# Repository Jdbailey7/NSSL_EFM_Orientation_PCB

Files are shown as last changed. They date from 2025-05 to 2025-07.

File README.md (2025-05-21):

# NSSL EFM Orientation PCB

In the paddle opposite the motor driver, an orientation sensor based on a simple IMU  
provides rough data on the instrument’s orientation over time. This allows analysis  
of pendulum motion and other movements of the full instrument package. The system is  
designed for easy sensor replacement, and all orientation data are logged to a  
microSD card.

See the [main instrument repo](https://github.com/LeemanGeophysicalLLC/NSSL_EFM_Instrument)
for documentation and the rest of the instrument.

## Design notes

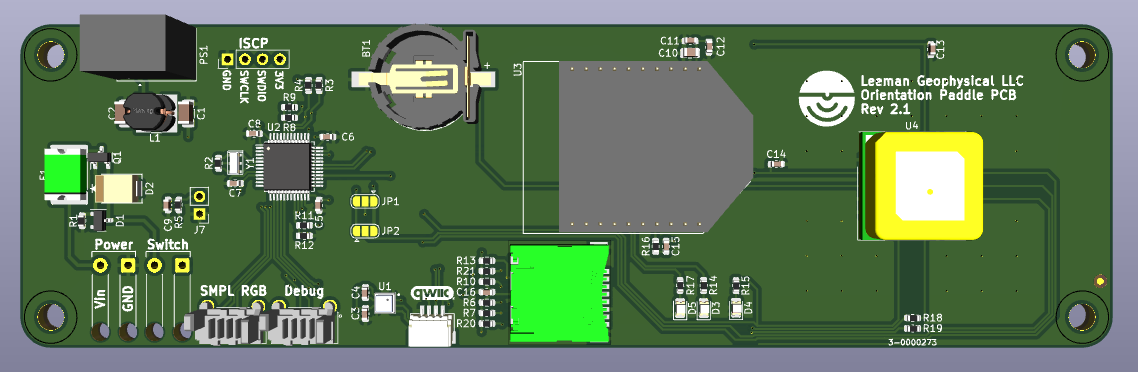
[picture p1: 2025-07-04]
Renders/pcb_front.png

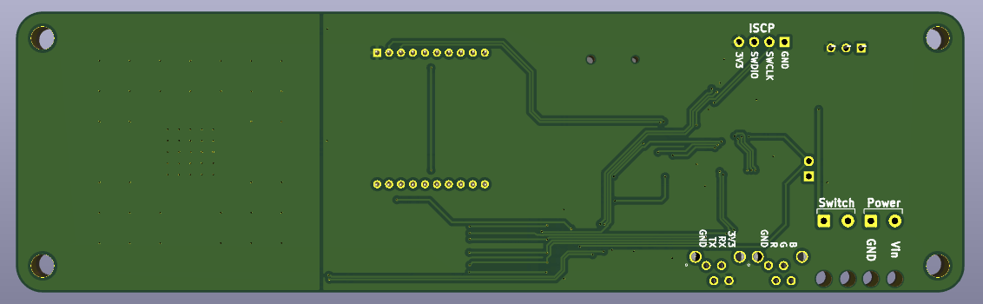
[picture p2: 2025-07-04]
Renders/pcb_back.png

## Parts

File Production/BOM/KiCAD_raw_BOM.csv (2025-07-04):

Reference | Value | Internal Part Number | PValue | Populated
BT1 | 1-0000246 | 1-0000246 | CR1220 | 1
C1 | 1-0000136 | 1-0000136 | 4.7uF | 1
C2 | 1-0000136 | 1-0000136 | 4.7uF | 1
C3 | 1-0000007 | 1-0000007 | 0.1uF | 0
C4 | 1-0000007 | 1-0000007 | 0.1uF | 0
C5 | 1-0000007 | 1-0000007 | 0.1uF | 1
C6 | 1-0000007 | 1-0000007 | 0.1uF | 1
C7 | 1-0000007 | 1-0000007 | 0.1uF | 1
C8 | 1-0000007 | 1-0000007 | 0.1uF | 1
C9 | 1-0000007 | 1-0000007 | 0.1uF | 1
C10 | 1-0000075 | 1-0000075 | 10uF | 0
C11 | 1-0000018 | 1-0000018 | 1uF | 0
C12 | 1-0000007 | 1-0000007 | 0.1uF | 0
C13 | 1-0000007 | 1-0000007 | 0.1uF | 1
C14 | 1-0000007 | 1-0000007 | 0.1uF | 1
C15 | 1-0000007 | 1-0000007 | 0.1uF | 0
C16 | 1-0000007 | 1-0000007 | 0.1uF | 1
D1 | 1-0001672 | 1-0001672 | BZX84C15 | 1
D2 | 1-0001537 | 1-0001537 | SMBJ64A | 1
D3 | 1-0000599 | 1-0000599 | Blue | 0
D4 | 1-0000601 | 1-0000601 | Yellow | 1
D5 | 1-0000601 | 1-0000601 | Yellow | 0
F1 | 1-0001517 | 1-0001517 | 1A | 1
FID1 | Fiducial_1mm_2mm | 0-0000000 | Fiducial | 0
FID2 | Fiducial_1mm_2mm | 0-0000000 | Fiducial | 0
J1 | 1-0001205 | 1-0001205 | Qwiic | 1
J2 | 1-0001156 | 1-0001156 | 4 Pos | 1
J3 | 1-0001156 | 1-0001156 | 4 Pos | 1
J4 | NP_Conn_01x02_Relief | 0-0000000 | NP_Conn_01x02 | 0
J5 | NP_Conn_01x02_Relief | 0-0000000 | NP_Conn_01x02 | 0
J6 | NP_Conn_01x04 | 0-0000000 | ISCP | 0
J7 | NP_Conn_01x02 | 0-0000000 | Reset | 0
J8 | 1-0000050 | 1-0000050 | XBee Socket | 0
J9 | 1-0000190 | 1-0000190 | DM3CS | 1
JP1 | SolderJumper_3_Bridged12 | 0-0000000 | Solder Jumper | 0
JP2 | SolderJumper_3_Bridged12 | 0-0000000 | Solder Jumper | 0
L1 | 1-0000931 | 1-0000931 | 3.3uH | 1
PCB1 | barepcb | 3-0000273 | Bare PCB | 1
PS1 | 1-0000727 | 1-0000727 | TSR 0.5 | 1
Q1 | 1-0001670 | 1-0001670 | SQ2337ES | 1
R1 | 1-0000174 | 1-0000174 | 100k | 1
R2 | 1-0000009 | 1-0000009 | NP | 0
R3 | 1-0000010 | 1-0000010 | 10k | 1
R4 | 1-0000010 | 1-0000010 | 10k | 1
R5 | 1-0000010 | 1-0000010 | 10k | 1
R6 | 1-0000010 | 1-0000010 | 10k | 1
R7 | 1-0000010 | 1-0000010 | 10k | 1
R8 | 1-0000006 | 1-0000006 | NP | 0
R9 | 1-0000174 | 1-0000174 | 100k | 1
R10 | 1-0000010 | 1-0000010 | 10k | 1
R11 | 1-0000006 | 1-0000006 | NP | 0
R12 | 1-0000174 | 1-0000174 | 100k | 1
R13 | 1-0000010 | 1-0000010 | 10k | 1
R14 | 1-0000008 | 1-0000008 | 150 | 0
R15 | 1-0000008 | 1-0000008 | 150 | 1
R16 | 1-0000006 | 1-0000006 | NP | 0
R17 | 1-0000008 | 1-0000008 | 150 | 0
R18 | 1-0000006 | 1-0000006 | 0R0 | 1
R19 | 1-0000006 | 1-0000006 | 0R0 | 1
R20 | 1-0000174 | 1-0000174 | 100k | 1
R21 | 1-0000174 | 1-0000174 | 100k | 1
U1 | 1-0001471 | 1-0001471 | BME688 | 0
U2 | 1-0000207 | 1-0000207 | STM32F103 | 1
U3 | 1-0000785 | 1-0000785 | XB3-24 | 0
U4 | 1-0000446 | 1-0000446 | SAM-M8Q-0-10 | 1
Y1 | 1-0000721 | 1-0000721 | 8MHz | 1

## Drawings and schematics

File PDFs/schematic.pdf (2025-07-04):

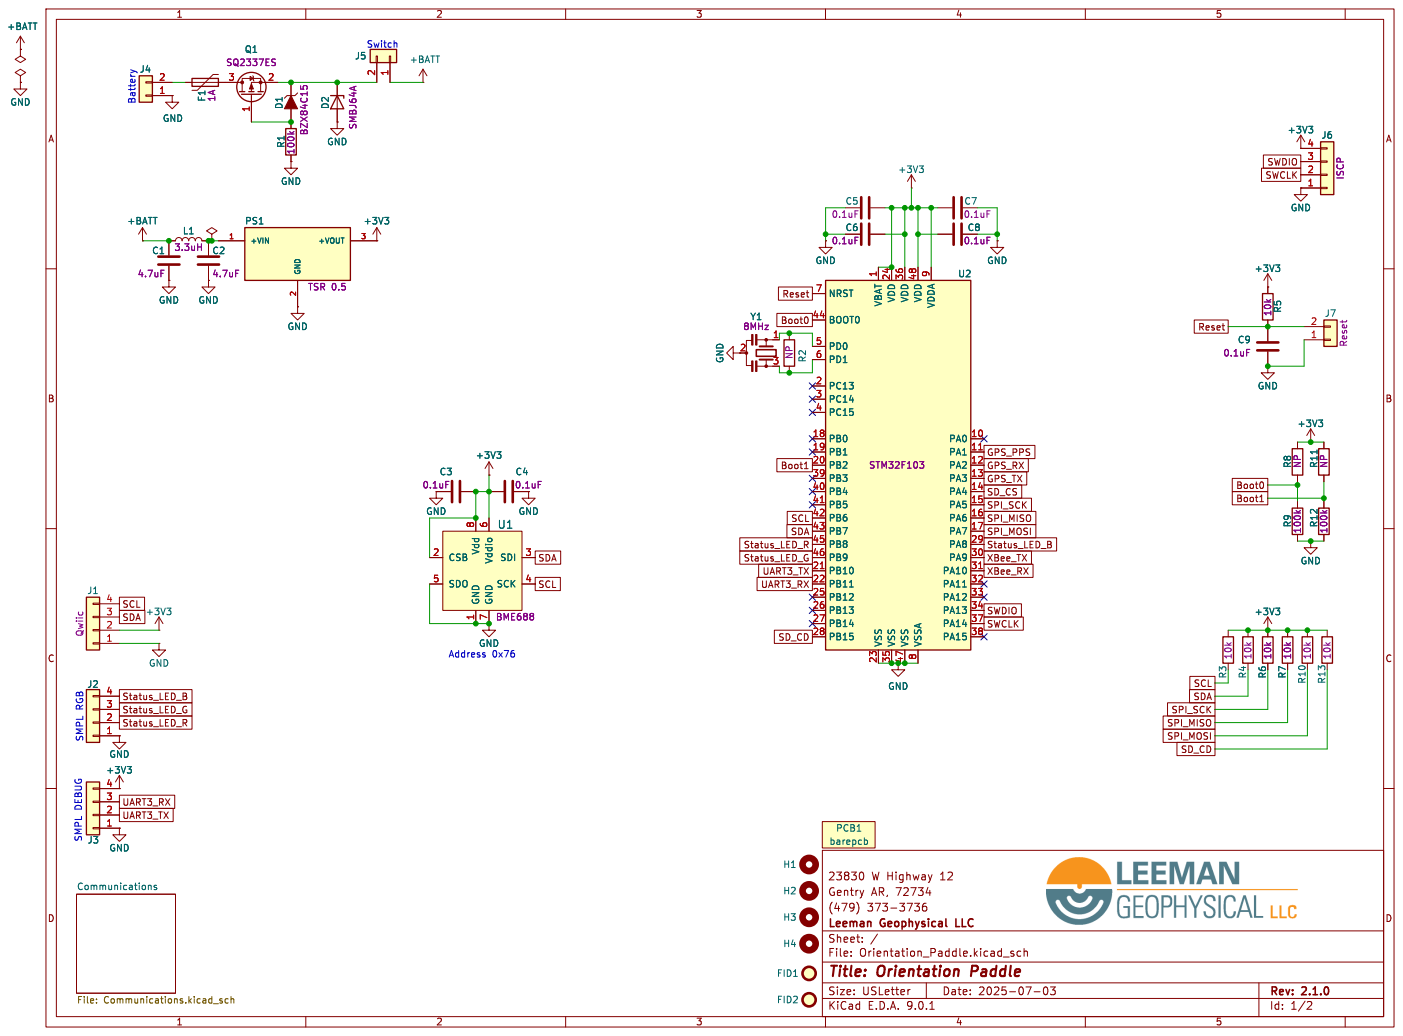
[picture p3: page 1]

Id: 1/2 Title: Orientation Paddle

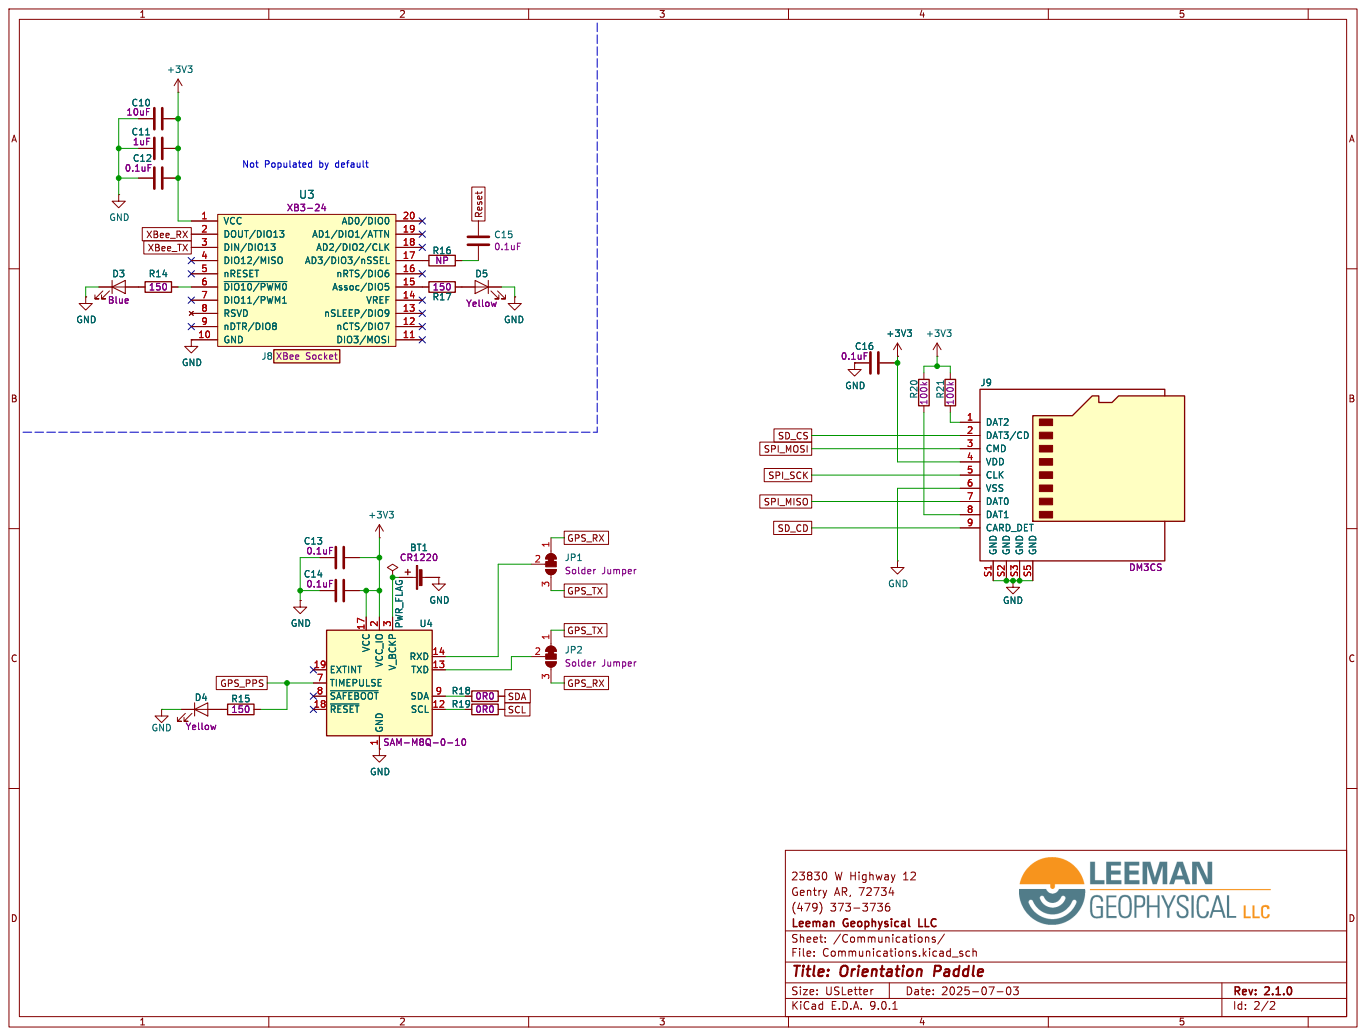
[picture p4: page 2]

J8 XBee Socket GND GND

Id: 2/2 Title: Orientation Paddle

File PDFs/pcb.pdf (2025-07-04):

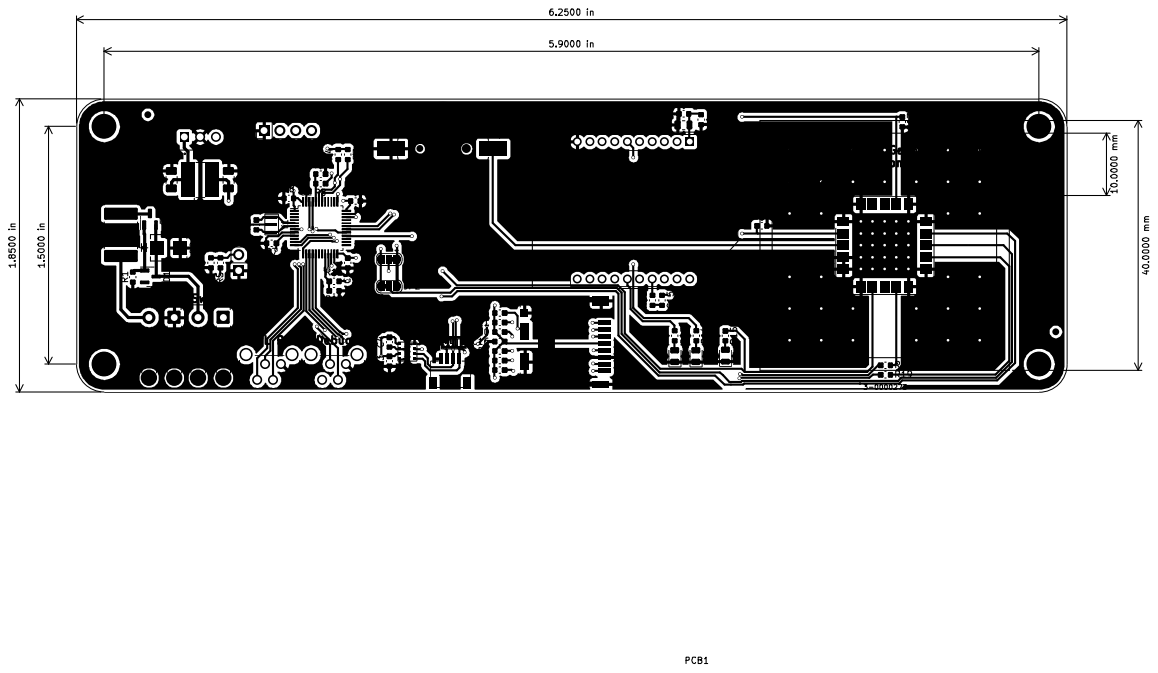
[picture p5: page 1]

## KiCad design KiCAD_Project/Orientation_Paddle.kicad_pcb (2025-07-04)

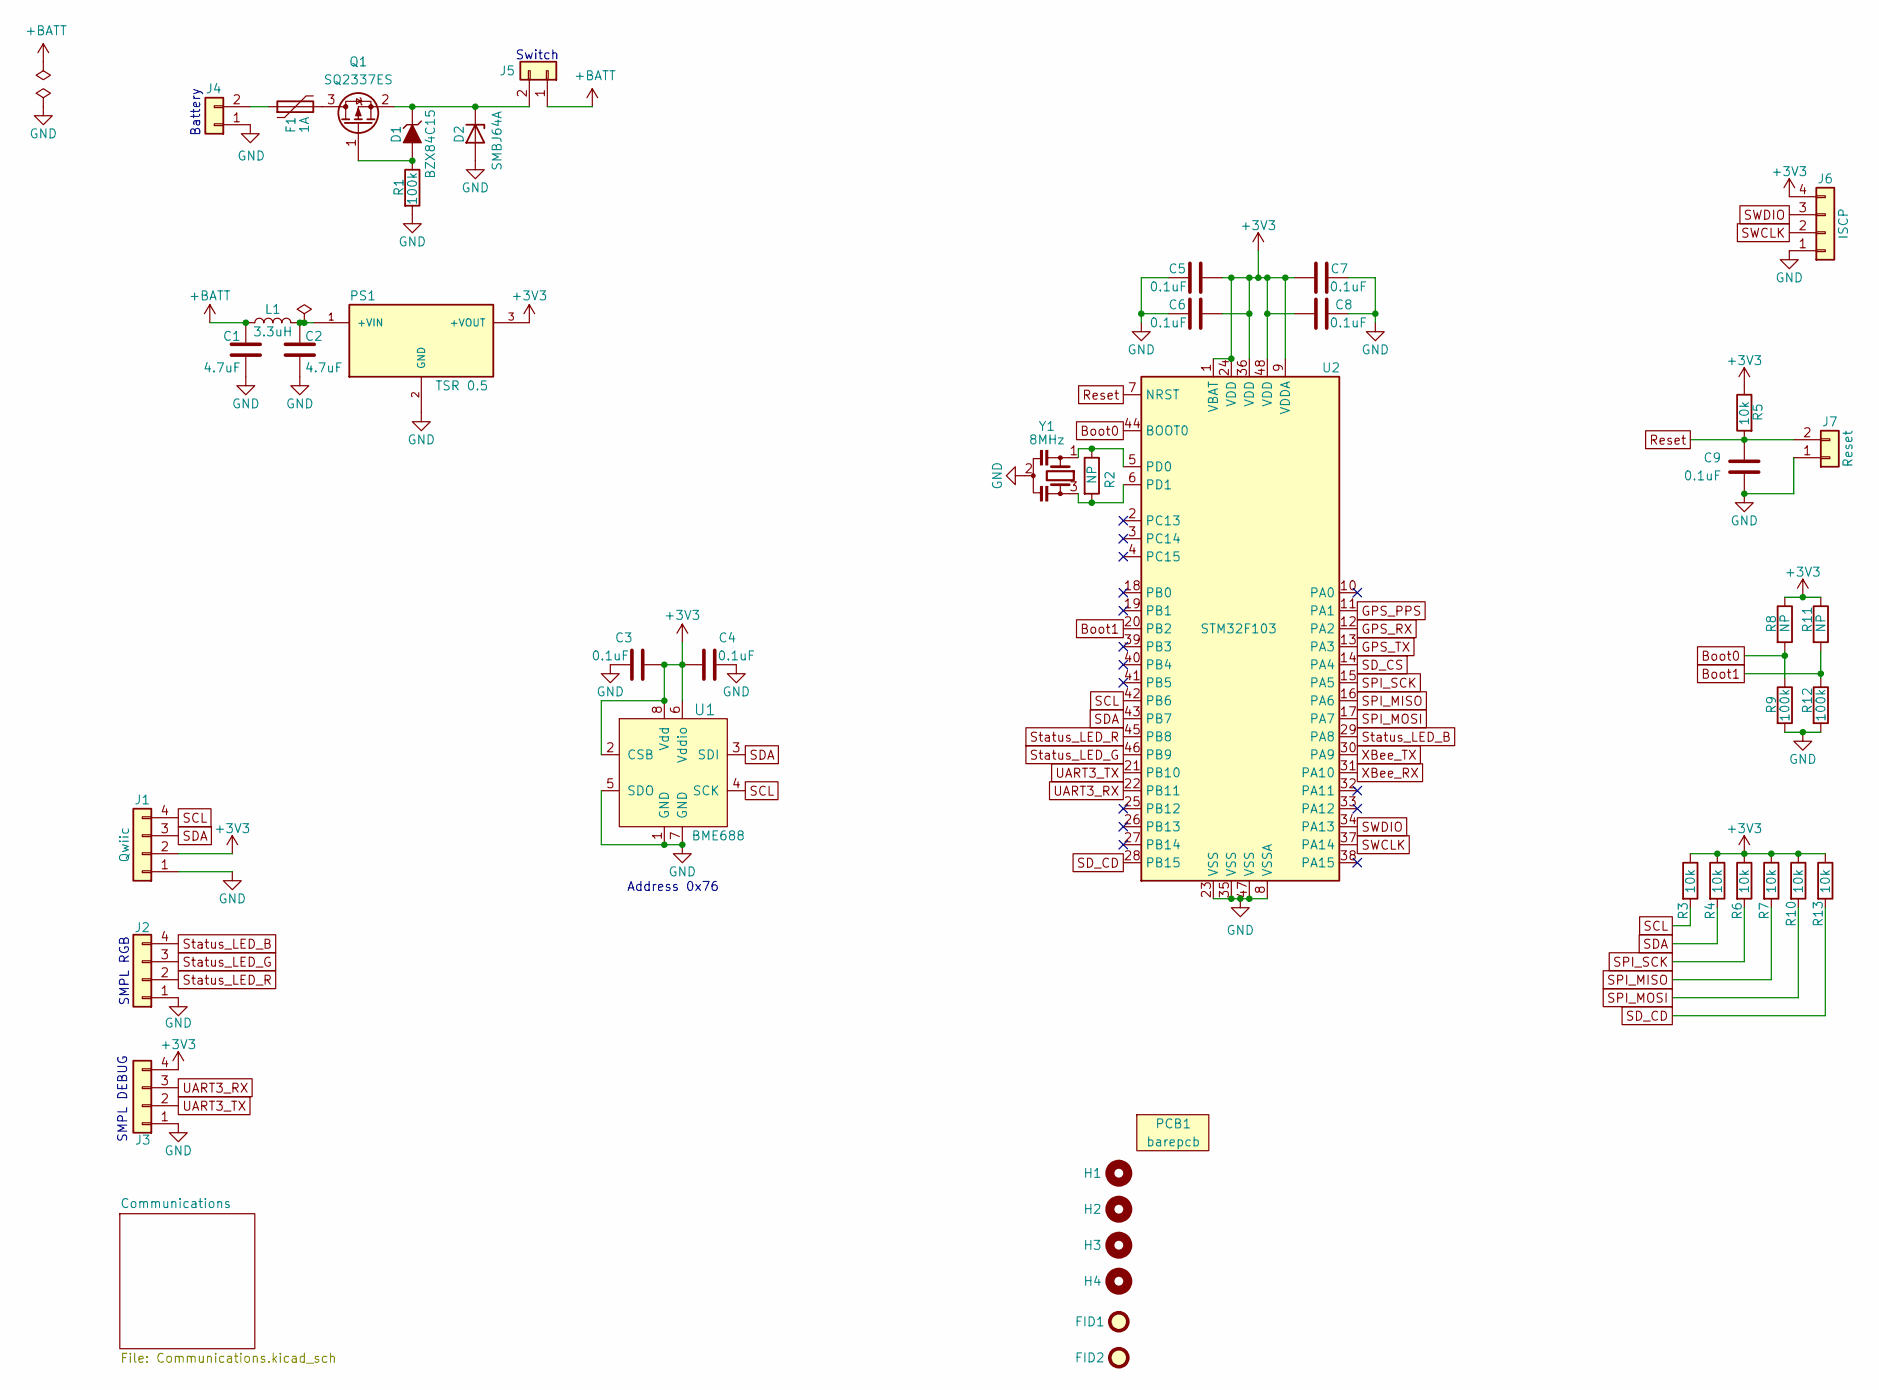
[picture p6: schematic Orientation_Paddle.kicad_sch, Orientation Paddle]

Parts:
C1, C2: 1-0000136
C3, C4, C5, C6, C7, C8, C9: 1-0000007
D1: 1-0001672
D2: 1-0001537
F1: 1-0001517
FID1, FID2: Fiducial_1mm_2mm; Fiducial_1mm_Mask2mm
H1, H2, H3, H4: Imperial6; MountingHole_imperial6
J1: 1-0001205
J2, J3: 1-0001156
J4, J5: NP_Conn_01x02_Relief; SolderWire_1x02_Relief
J6: NP_Conn_01x04; PinHeader_1x04_P2.54mm_Vertical
J7: NP_Conn_01x02; PinHeader_1x02_P2.54mm_Vertical
L1: 1-0000931
PCB1: barepcb
PS1: 1-0000727
Q1: 1-0001670
R1, R9, R12: 1-0000174
R2: 1-0000009
R3, R4, R5, R6, R7, R10, R13: 1-0000010
R8, R11: 1-0000006
U1: 1-0001471
U2: 1-0000207
Y1: 1-0000721

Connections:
+3V3: C3.2, C4.1, C5.1, C6.1, C7.1, C8.1, J1.2, J3.4, J6.4, PS1.3 (+VOUT), R3.1, R4.1, R5.1, R6.1, R7.1, R8.1, R10.1, R11.1, R13.1, U1.2 (CSB), U1.6 (Vddio), U1.8 (Vdd), U2.1 (VBAT), U2.9 (VDDA), U2.24 (VDD), U2.36 (VDD), U2.48 (VDD); also elsewhere on the board
+BATT: C1.1, J5.1, L1.1
Boot0: R8.2, R9.1, U2.44 (BOOT0)
Boot1: R11.2, R12.1, U2.20 (PB2)
GND: C1.2, C2.2, C3.1, C4.2, C5.2, C6.2, C7.2, C8.2, C9.2, D2.2 (A), J1.1, J2.1, J3.1, J4.1, J6.1, J7.1, PS1.2 (GND), R1.2, R9.2, R12.2, U1.1 (GND), U1.5 (SDO), U1.7 (GND), U2.8 (VSSA), U2.23 (VSS), U2.35 (VSS), U2.47 (VSS), Y1.2; also elsewhere on the board
GPS_PPS: U2.11 (PA1); also elsewhere on the board
GPS_RX: U2.12 (PA2); also elsewhere on the board
GPS_TX: U2.13 (PA3); also elsewhere on the board
unnamed: D1.1 (A), Q1.1 (G), R1.1
unnamed: D1.3 (K), D2.1 (K), J5.2, Q1.2 (S)
unnamed: F1.1, J4.2
unnamed: C2.1, L1.2, PS1.1 (+VIN)
unnamed: F1.2, Q1.3 (D)
unnamed: R2.1, U2.5 (PD0), Y1.1
unnamed: R2.2, U2.6 (PD1), Y1.3
Reset: C9.1, J7.2, R5.2, U2.7 (NRST); also elsewhere on the board
SCL: J1.4, R3.2, U1.4 (SCK), U2.42 (PB6); also elsewhere on the board
SDA: J1.3, R4.2, U1.3 (SDI), U2.43 (PB7); also elsewhere on the board
SD_CD: R13.2, U2.28 (PB15); also elsewhere on the board
SD_CS: U2.14 (PA4); also elsewhere on the board
SPI_MISO: R7.2, U2.16 (PA6); also elsewhere on the board
SPI_MOSI: R10.2, U2.17 (PA7); also elsewhere on the board
SPI_SCK: R6.2, U2.15 (PA5); also elsewhere on the board
SWCLK: J6.2, U2.37 (PA14)
SWDIO: J6.3, U2.34 (PA13)
Status_LED_B: J2.4, U2.29 (PA8)
Status_LED_G: J2.3, U2.46 (PB9)
Status_LED_R: J2.2, U2.45 (PB8)
UART3_RX: J3.3, U2.22 (PB11)
UART3_TX: J3.2, U2.21 (PB10)
XBee_RX: U2.31 (PA10); also elsewhere on the board
XBee_TX: U2.30 (PA9); also elsewhere on the board

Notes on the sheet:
Battery
Address 0x76
SMPL DEBUG
Switch
SMPL RGB

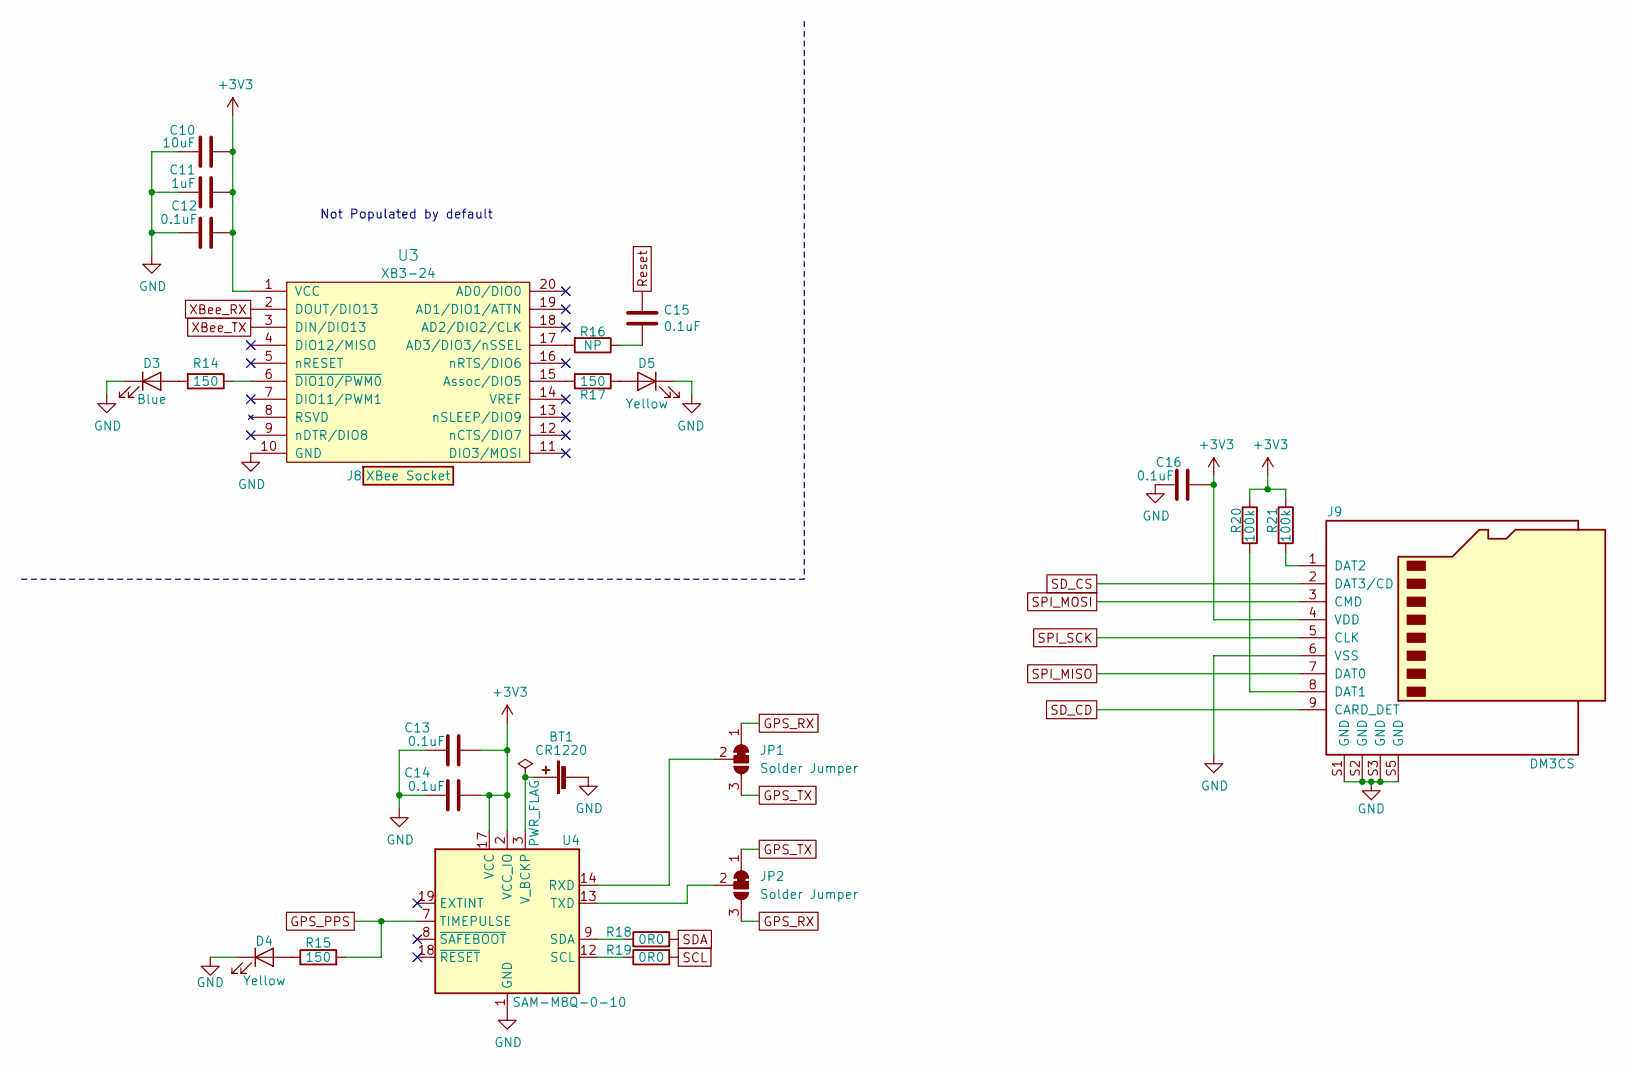
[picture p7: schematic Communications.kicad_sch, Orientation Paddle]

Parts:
BT1: 1-0000246
C10: 1-0000075
C11: 1-0000018
C12, C13, C14, C15, C16: 1-0000007
D3: 1-0000599
D4, D5: 1-0000601
J8: 1-0000050
J9: 1-0000190
JP1, JP2: SolderJumper_3_Bridged12; SolderJumper-3_P1.3mm_Bridged12_RoundedPad1.0x1.5mm
R14, R15, R17: 1-0000008
R16, R18, R19: 1-0000006
R20, R21: 1-0000174
U3: 1-0000785
U4: 1-0000446

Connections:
+3V3: C10.1, C11.1, C12.1, C13.1, C14.1, C16.2, J9.4 (VDD), R20.1, R21.1, U3.1 (VCC), U4.2 (VCC_IO), U4.17 (VCC); also elsewhere on the board
GND: BT1.2 (-), C10.2, C11.2, C12.2, C13.2, C14.2, C16.1, D3.1 (K), D4.1 (K), D5.1 (K), J9.6 (VSS), J9.S1 (GND), J9.S2 (GND), J9.S3 (GND), J9.S5 (GND), U3.10 (GND), U4.1 (GND), U4.4 (GND), U4.5 (GND), U4.6 (GND), U4.10 (GND), U4.11 (GND), U4.15 (GND), U4.16 (GND), U4.20 (GND); also elsewhere on the board
GPS_PPS: R15.2, U4.7 (TIMEPULSE); also elsewhere on the board
GPS_RX: JP1.1 (A), JP2.3 (B); also elsewhere on the board
GPS_TX: JP1.3 (B), JP2.1 (A); also elsewhere on the board
unnamed: BT1.1 (+), U4.3 (V_BCKP)
unnamed: C15.2, R16.1
unnamed: D3.2 (A), R14.2
unnamed: D4.2 (A), R15.1
unnamed: D5.2 (A), R17.1
unnamed: J9.8 (DAT1), R20.2
unnamed: J9.1 (DAT2), R21.2
unnamed: JP1.2 (C), U4.14 (RXD)
unnamed: JP2.2 (C), U4.13 (TXD)
unnamed: R16.2, U3.17 (AD3/DIO3/nSSEL)
unnamed: R17.2, U3.15 (Assoc/DIO5)
unnamed: R14.1, U3.6 (~DIO10/PWM0)
unnamed: R19.1, U4.12 (SCL)
unnamed: R18.1, U4.9 (SDA)
Reset: C15.1; also elsewhere on the board
SCL: R19.2; also elsewhere on the board
SDA: R18.2; also elsewhere on the board
SD_CD: J9.9 (CARD_DET); also elsewhere on the board
SD_CS: J9.2 (DAT3/CD); also elsewhere on the board
SPI_MISO: J9.7 (DAT0); also elsewhere on the board
SPI_MOSI: J9.3 (CMD); also elsewhere on the board
SPI_SCK: J9.5 (CLK); also elsewhere on the board
XBee_RX: U3.2 (DOUT/DIO13); also elsewhere on the board
XBee_TX: U3.3 (DIN/DIO13); also elsewhere on the board

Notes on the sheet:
Not Populated by default

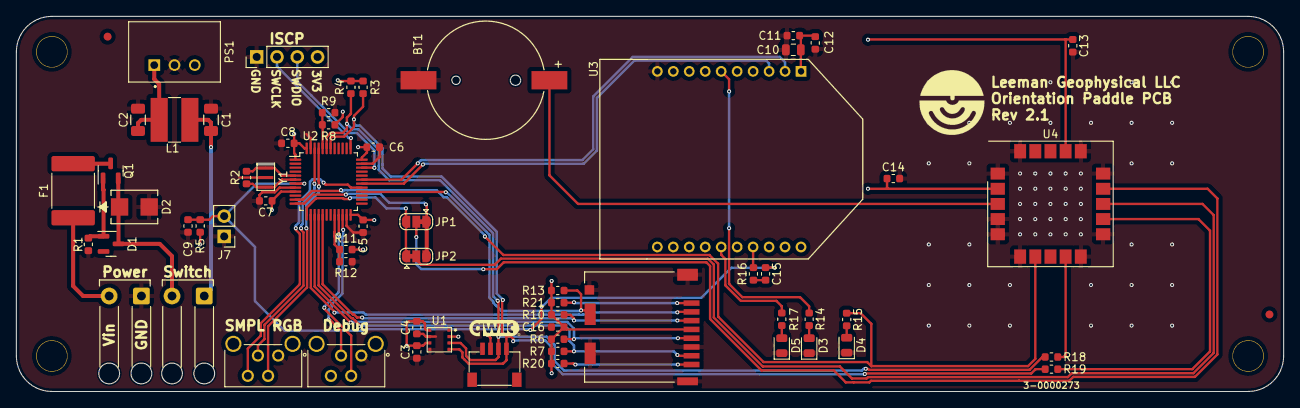
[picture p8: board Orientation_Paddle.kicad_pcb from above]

Board: 2 copper layers, 158.7 x 47.0 mm, 70 parts (0 on the bottom side), 46 nets.

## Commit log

2025-06-02 Version 1.0 as built
    [Communications.kicad_sch, KiCAD_raw_BOM.csv, Orientation_Paddle.kicad_pcb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]
2025-06-03 Rev 2.0 Changes: Fixed the following issues, - Issue #7 (Added RP Protection) - Issue #6 (Removed old encoder and sense connections) - Issue #5 (Solidified Serial connections by removing jumpers) - I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
    [Communications.kicad_sch, Orientation_Paddle.kicad_pcb, Orientation_Paddle.kicad_sch]
2025-06-03 Make Rev 2.0 production files
    [Communications.kicad_sch, KiCAD_raw_BOM.csv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]
2025-07-03 Fixed Issues #9, Issue #10 (Rev2.1)
    [Communications.kicad_sch, Orientation_Paddle.kicad_pcb, Orientation_Paddle.kicad_sch]
2025-07-04 Add serial jumpers for GPS and make production files for Rev 2.1
    [Communications.kicad_sch, KiCAD_raw_BOM.csv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]
